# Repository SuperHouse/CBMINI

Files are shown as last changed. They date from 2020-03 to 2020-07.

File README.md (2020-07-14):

Chair Control Breakout Mini
===========================

Connects between an electric wheelchair input device and the chair
controller, so that the input device can be read by an Arduino and
redirected to another system.

The output can be isolated so that the chair won't receive the input
signals, preventing it from moving while the input is being used for
another purpose such as controlling a computer or remote control
device.

The breakout can send the output to either a connected USB host such
as a computer, or other devices via CAN bus so the wheelchair controls
can be used to fly a drone or drive a remote control car.

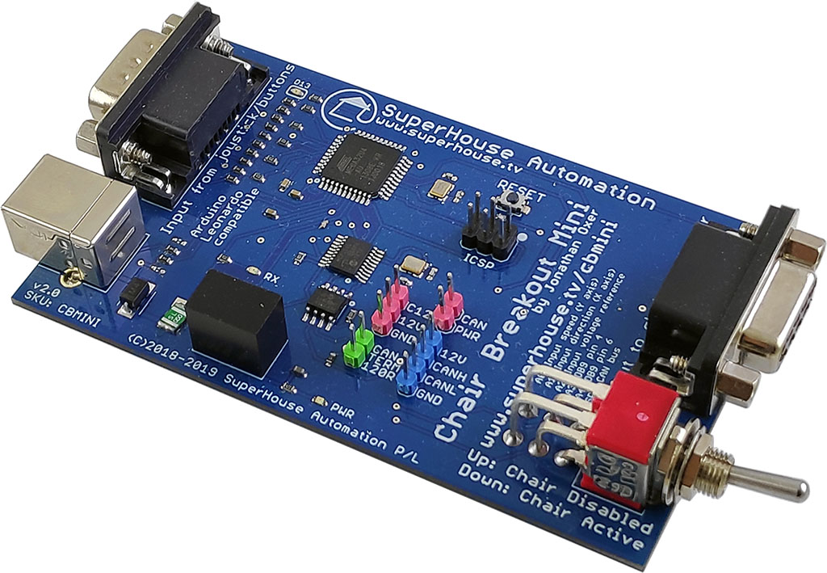
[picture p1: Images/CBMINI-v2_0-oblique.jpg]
Chair Breakout Mini


Features:

 * 1 x input device connection.
 * 1 x input device pass-through output
 * CAN bus
 * Can derives 12V power from the host wheelchair controller or separately

More information is available at:

  http://www.superhouse.tv/cbmini

Hardware
--------
The "Hardware" directory contains the PCB design as an EAGLE project.
EAGLE PCB design software is available from Autodesk free for
non-commercial use.

Firmware
--------
The "Firmware" directory contains example firmware as an Arduino
project.

Credits
-------
Jonathan Oxer jon@oxer.com.au

License
-------
Copyright 2017-2020 SuperHouse Automation Pty Ltd  www.superhouse.tv  

The hardware portion of this project is licensed under the TAPR Open
Hardware License (www.tapr.org/OHL). The "license" folder within this
repository contains a copy of this license in plain text format.

The software portion of this project is licensed under the Simplified
BSD License. The "licence" folder within this project contains a
copy of this license in plain text format.

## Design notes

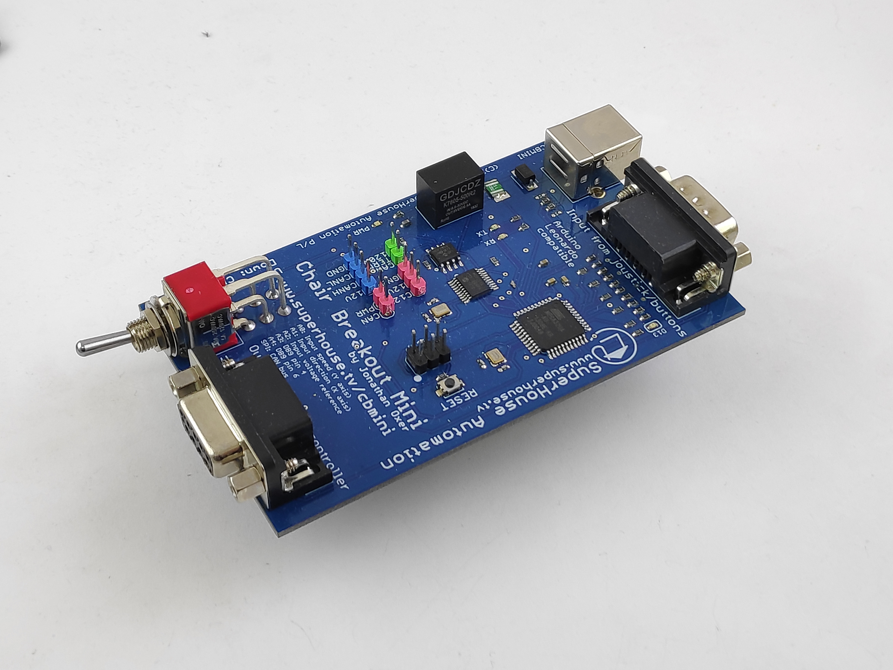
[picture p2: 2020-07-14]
Images/2019-11-09 11.39.07.jpg

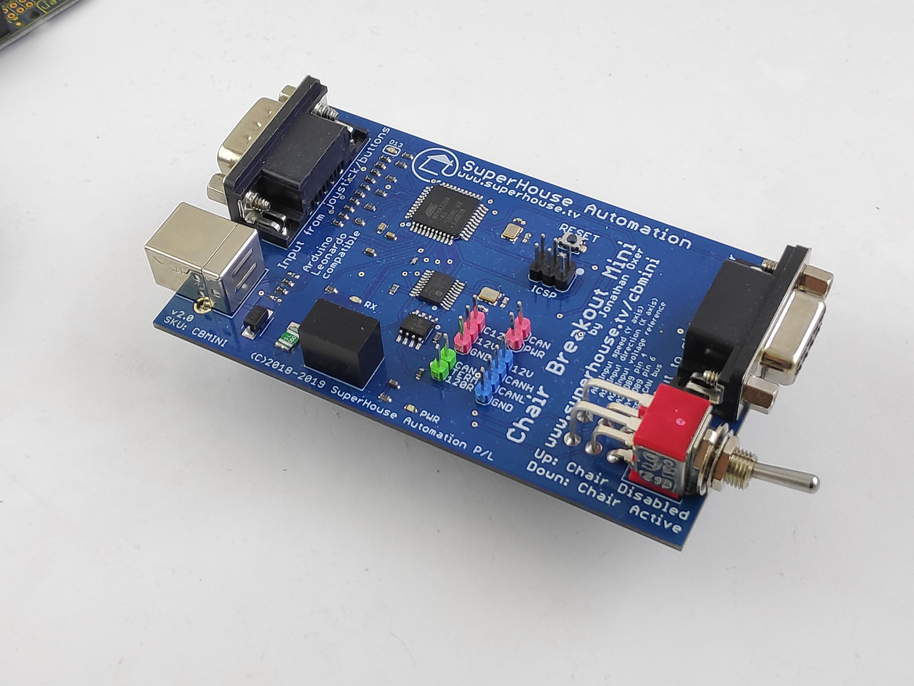
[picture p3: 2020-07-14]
Images/2019-11-09 11.39.31.jpg

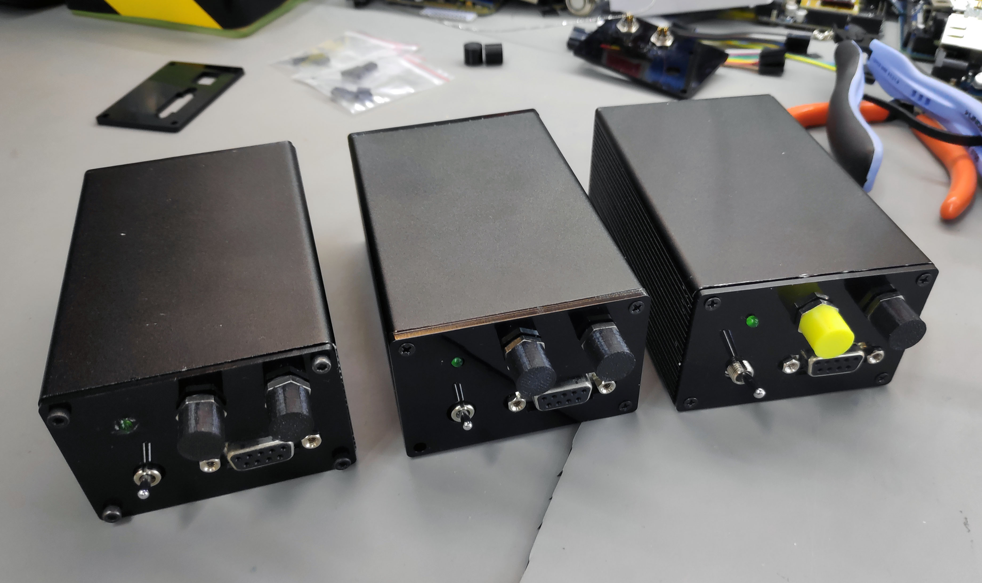
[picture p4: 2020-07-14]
Images/2019-04-25 10.59.25.jpg

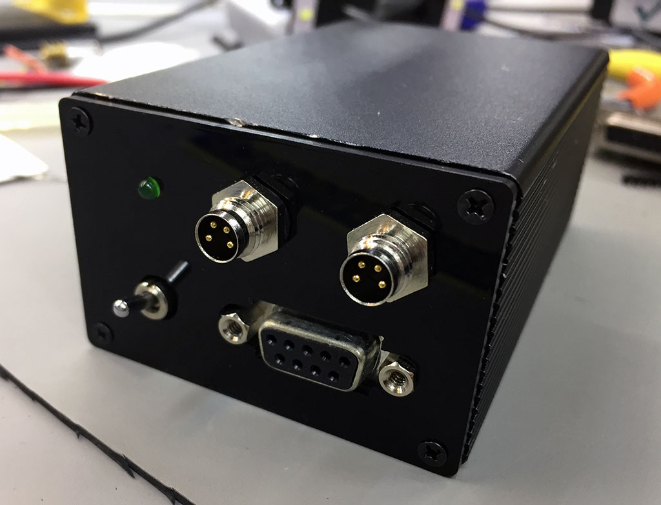
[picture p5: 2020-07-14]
Images/CBMINI-on-bench.jpg

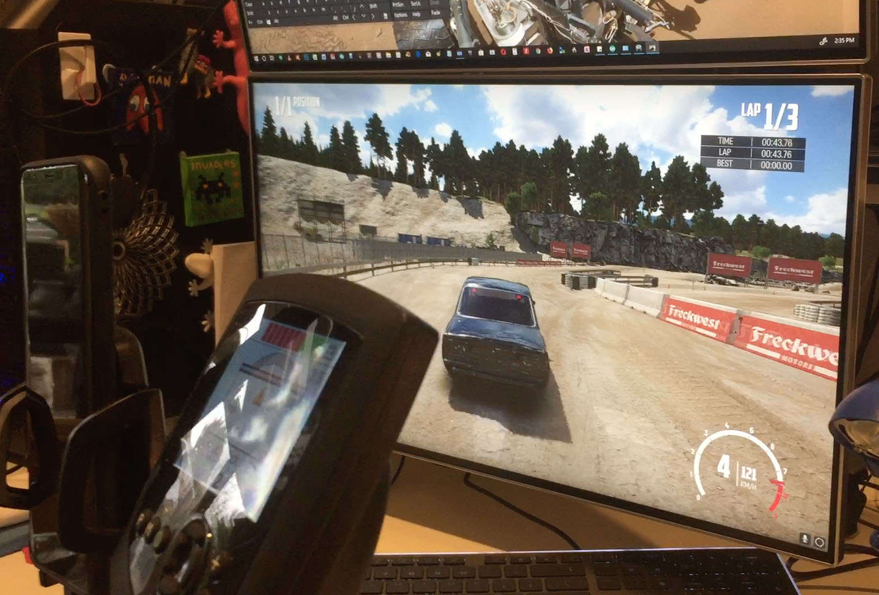
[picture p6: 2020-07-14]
Images/car-game.jpg

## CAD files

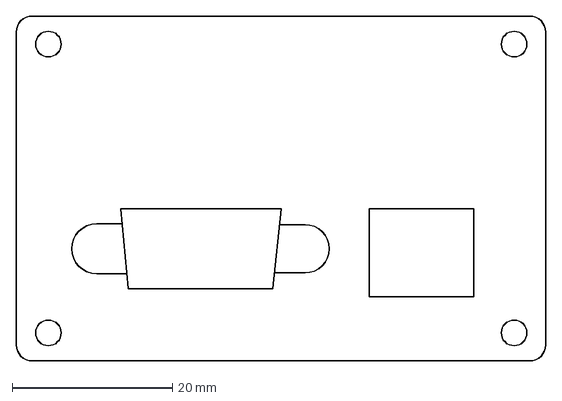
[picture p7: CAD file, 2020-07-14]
Enclosure/Left End Plate v8.dxf
66.0 x 43.0 mm

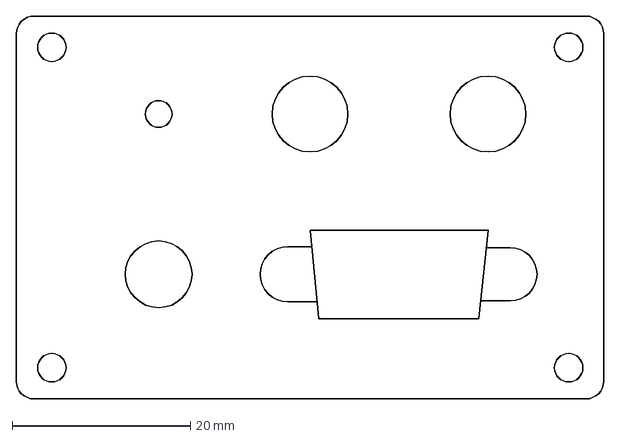
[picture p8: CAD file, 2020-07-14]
Enclosure/Right End Plate v6.dxf
66.0 x 43.0 mm

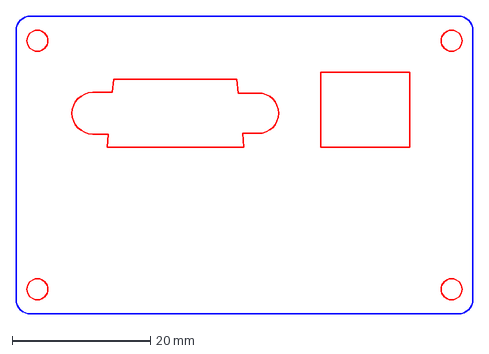
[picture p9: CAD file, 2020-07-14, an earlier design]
Enclosure/Left End Plate v5.dxf
66.2 x 43.2 mm

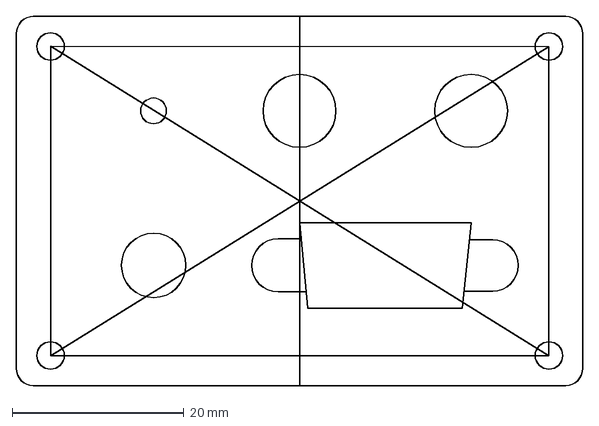
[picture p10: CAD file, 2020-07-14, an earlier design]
Enclosure/Right End Plate v5.dxf
66.0 x 43.0 mm

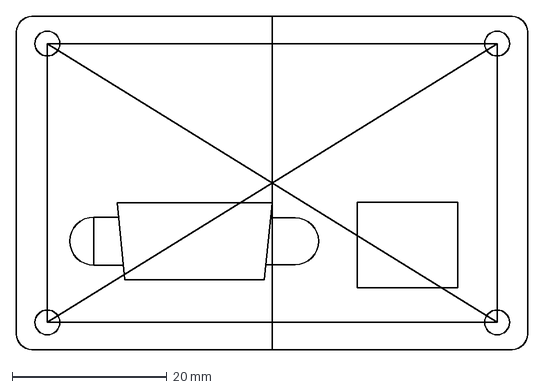
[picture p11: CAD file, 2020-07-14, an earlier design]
Enclosure/Left End Plate v7.dxf
66.0 x 43.0 mm

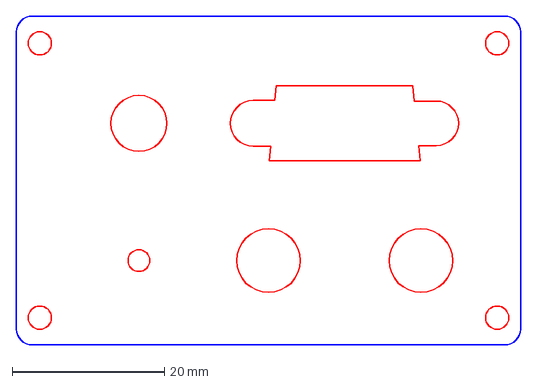
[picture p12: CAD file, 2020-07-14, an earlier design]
Enclosure/Right End Plate v3.dxf
66.2 x 43.2 mm

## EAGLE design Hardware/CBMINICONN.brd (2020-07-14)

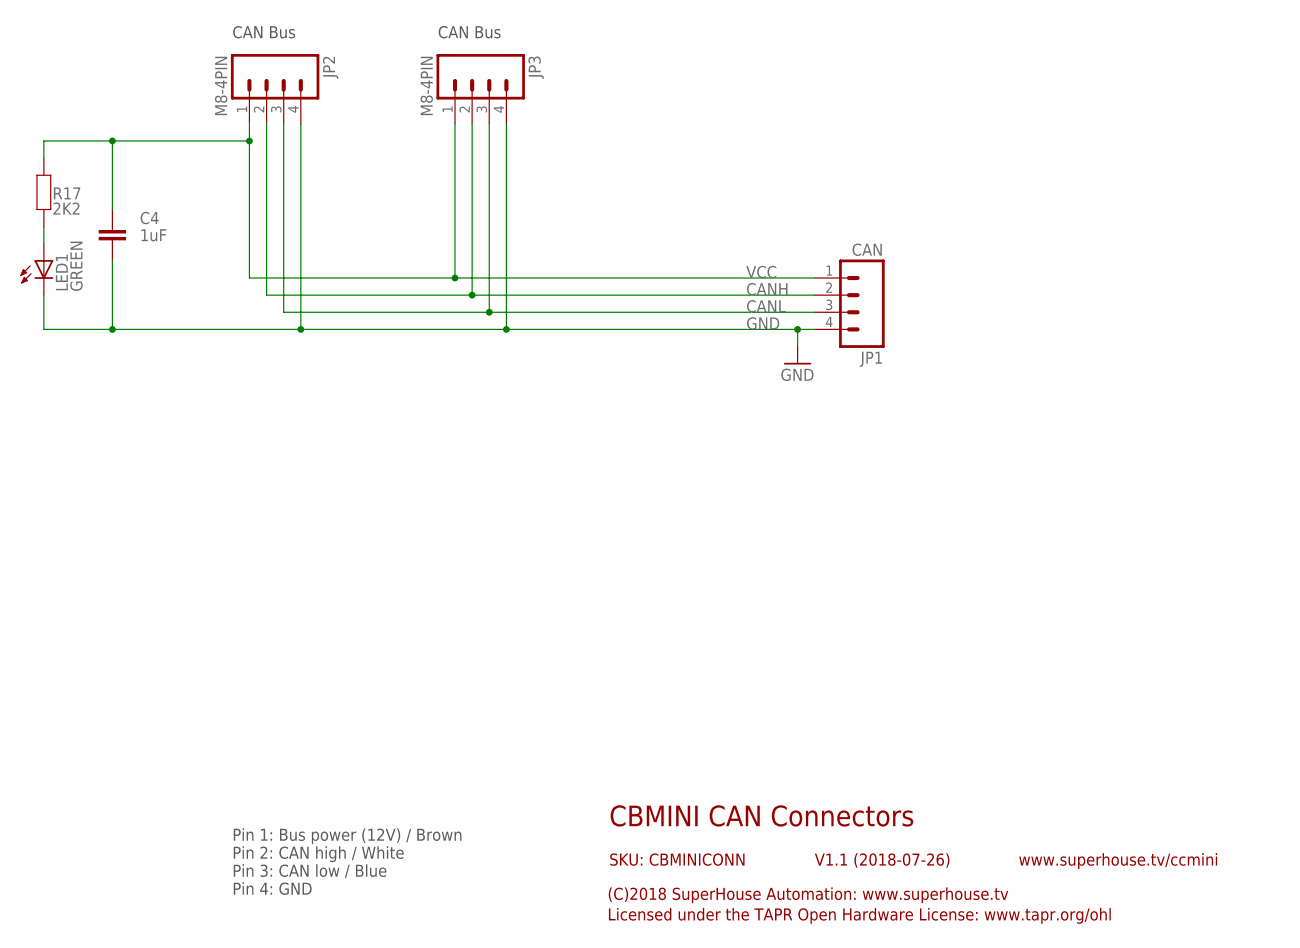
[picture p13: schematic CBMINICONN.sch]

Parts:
C4: 1uF; 0603
JP1: CAN; 1X04
JP2, JP3: M8-4PIN
LED1: GREEN; LED3MM
R17: 2K2; 0603

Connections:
CANH: JP1.2, JP2.2, JP3.2
CANL: JP1.3, JP2.3, JP3.3
GND: C4.1, JP1.4, JP2.4, JP3.4, LED1.K (C)
unnamed: LED1.A, R17.1
VCC: C4.2, JP1.1, JP2.1, JP3.1, R17.2

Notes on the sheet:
CBMINI CAN Connectors
V1.1 (2018-07-26)
SKU: CBMINICONN
(C)2018 SuperHouse Automation: www.superhouse.tv
Licensed under the TAPR Open Hardware License: www.tapr.org/ohl
www.superhouse.tv/ccmini
Pin 1: Bus power (12V) / Brown Pin 2: CAN high / White Pin 3: CAN low / Blue Pin 4: GND
CAN Bus

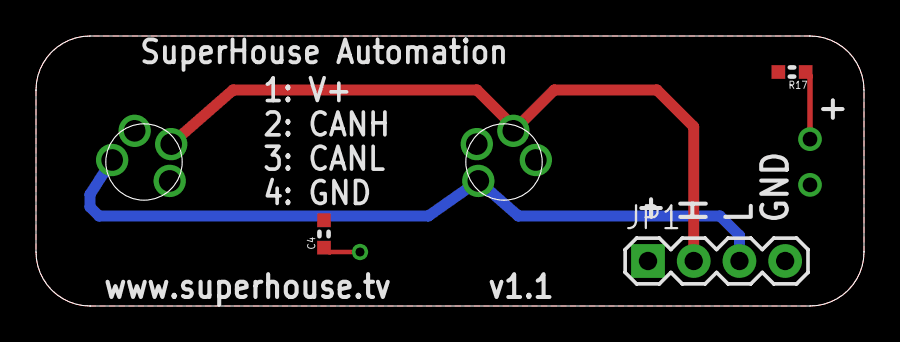
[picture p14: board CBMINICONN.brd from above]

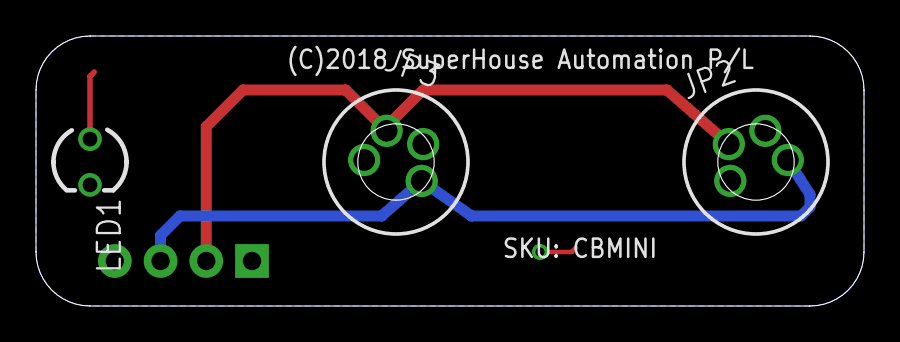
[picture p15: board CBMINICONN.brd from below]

Board: 2 copper layers, 46.0 x 15.0 mm, 6 parts (3 on the bottom side), 5 nets.

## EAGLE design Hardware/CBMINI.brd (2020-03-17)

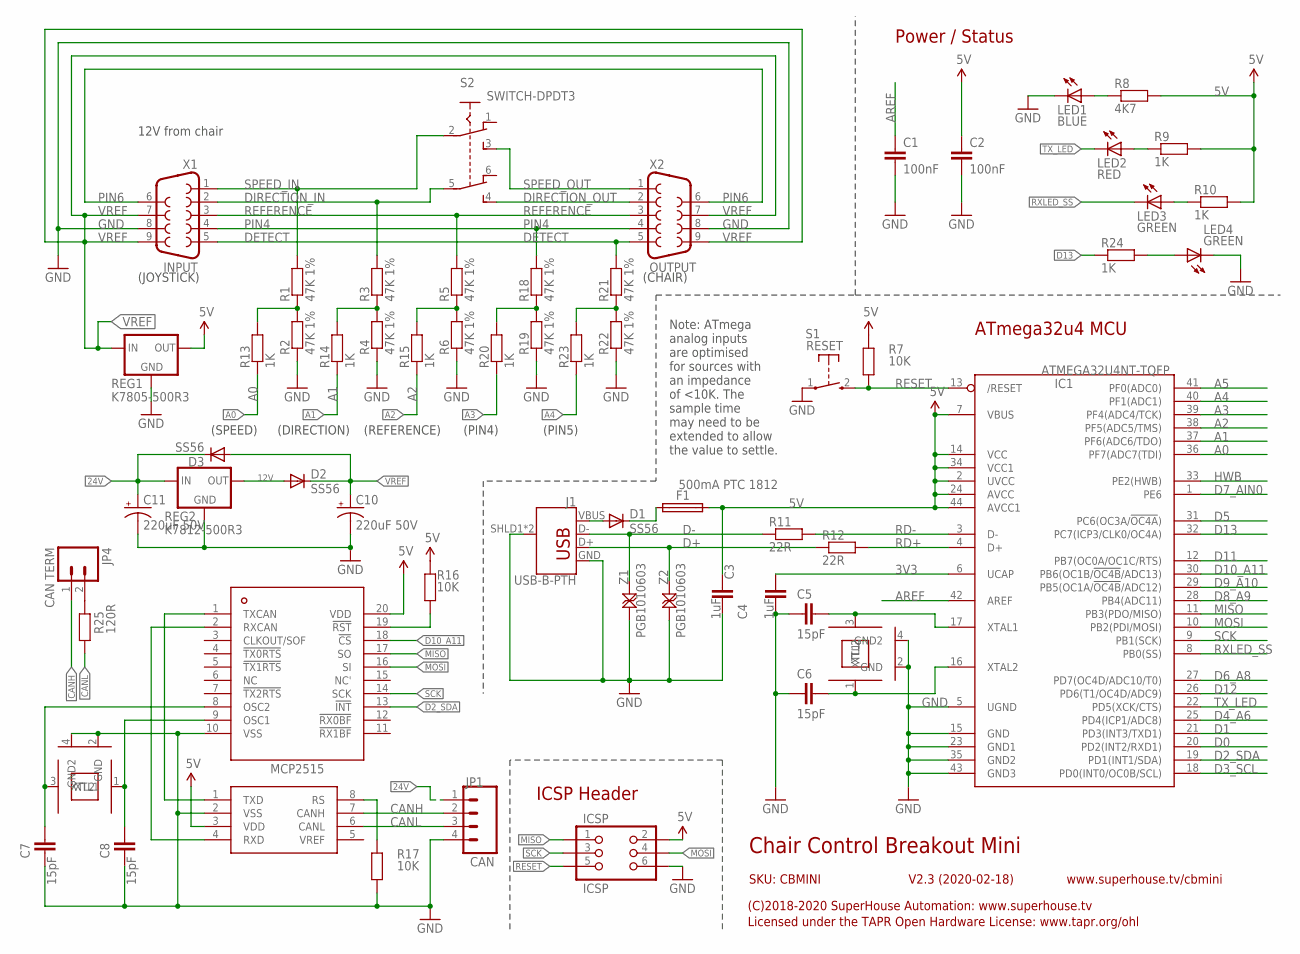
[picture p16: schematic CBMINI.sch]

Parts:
C1, C2: 100nF; C0603
C3, C4: 1uF; C0603
C5, C6, C7, C8: 15pF; C0603
C10, C11: 220uF 50V; PANASONIC_G
D1, D2, D3: SS56; SMA-DIODE
F1: 500mA PTC 1812; 1812
IC1: ATMEGA32U4NT-TQFP; TQFP44
IC2: MCP2515; TSSOP20
IC3: MCP2551; SO08
ICSP: ICSP; 2X03-ICSP
J1: USB-B-PTH
JP1: CAN; 1X04-P
JP4: CAN TERM; 1X02-P
LED1: BLUE; LED-0603
LED2: RED; LED-0603
LED3, LED4: GREEN; LED-0603
R1, R2, R3, R4, R5, R6, R18, R19, R21, R22: 47K 1%; R0603
R7, R16, R17: 10K; R0603
R8: 4K7; R0603
R9, R10, R13, R14, R15, R20, R23, R24: 1K; R0603
R11, R12: 22R; R0603
R25: 120R; R0603
REG1: K7805-500R3; K78XX-500R3
REG2: K7812-500R3; K78XX-500R3
S1: RESET; TACTILE_SMT_3X4X2
S2: SWITCH-DPDT3; 7201SD9AV2BE
X1: INPUT; DB9-PCB-PLUG
X2: OUTPUT; DB9-PCB-SOCKET
XTL1, XTL2: 16MHz; CRYSTAL-SMD-3X2
Z1, Z2: PGB1010603; TVS0603

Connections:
3V3: C4.2, IC1.6 (UCAP)
5V: C2.1, C3.1, F1.2, IC1.2 (UVCC), IC1.7 (VBUS), IC1.14 (VCC), IC1.24 (AVCC), IC1.34 (VCC1), IC1.44 (AVCC1), IC2.20 (VDD), IC3.3 (VDD), ICSP.2, R7.2, R8.2, R9.2, R10.2, R16.2, REG1.3 (OUT)
12V: D2.A, REG2.3 (OUT)
24V: C11.+, D3.C, JP1.1, REG2.1 (IN)
A0: IC1.36 (PF7(ADC7(TDI)), R13.1
A1: IC1.37 (PF6(ADC6/TDO)), R14.1
A2: IC1.38 (PF5(ADC5/TMS)), R15.1
A3: IC1.39 (PF4(ADC4/TCK)), R20.1
A4: IC1.40 (PF1(ADC1)), R23.1
A5: IC1.41 (PF0(ADC0))
AREF: C1.1, IC1.42 (AREF)
CANH: IC3.7 (CANH), JP1.2, JP4.1
CANL: IC3.6 (CANL), JP1.3, R25.1
D0: IC1.20 (PD2(INT2/RXD1))
D1: IC1.21 (PD3(INT3/TXD1))
D2_SDA: IC1.19 (PD1(INT1/SDA)), IC2.13 (!INT)
D3_SCL: IC1.18 (PD0(INT0/OC0B/SCL))
D4_A6: IC1.25 (PD4(ICP1/ADC8))
D5: IC1.31 (PC6(OC3A/!OC4A!))
D6_A8: IC1.27 (PD7(OC4D/ADC10/T0))
D7_AIN0: IC1.1 (PE6)
D8_A9: IC1.28 (PB4(ADC11))
D9_A10: IC1.29 (PB5(OC1A/!OC4B!/ADC12))
D10_A11: IC1.30 (PB6(OC1B/!OC4B!/ADC13)), IC2.18 (!CS)
D11: IC1.12 (PB7(OC0A/OC1C/RTS))
D12: IC1.26 (PD6(T1/OC4D/ADC9))
D13: IC1.32 (PC7(ICP3/CLK0/OC4A)), R24.1
D+: J1.D+, R12.1, Z2.2
D-: J1.D-, R11.1, Z1.2
DETECT: R21.2, X1.5, X2.5
DIRECTION_IN: R3.2, S2.5, X1.2
DIRECTION_OUT: S2.4, X2.2
GND: C1.2, C2.2, C3.2, C4.1, C5.1, C6.1, C7.1, C8.1, C10.-, C11.-, IC1.5 (UGND), IC1.15 (GND), IC1.23 (GND1), IC1.35 (GND2), IC1.43 (GND3), IC2.10 (VSS), IC3.2 (VSS), ICSP.6, J1.GND, J1.SHLD1 (SHIELD), J1.SHLD2 (SHIELD), JP1.4, LED1.C, LED4.C, R2.1, R4.1, R6.1, R17.1, R19.1, R22.1, REG1.2 (GND), REG2.2 (GND), S1.1, X1.8, X2.8, XTL1.2 (GND), XTL1.4 (GND2), XTL2.2 (GND), XTL2.4 (GND2), Z1.1, Z2.1
HWB: IC1.33 (PE2(HWB))
MISO: IC1.11 (PB3(PDO/MISO)), IC2.17 (SO), ICSP.1
MOSI: IC1.10 (PB2(PDI/MOSI)), IC2.16 (SI), ICSP.4
unnamed: LED4.A, R24.2
unnamed: R1.1, R2.2, R13.2
unnamed: R3.1, R4.2, R14.2
unnamed: R5.1, R6.2, R15.2
unnamed: LED1.A, R8.1
unnamed: LED2.A, R9.1
unnamed: LED3.A, R10.1
unnamed: IC2.1 (TXCAN), IC3.1 (TXD)
unnamed: IC2.19 (!RST), R16.1
unnamed: C5.2, IC1.17 (XTAL1), XTL1.3 (XTL2)
unnamed: C6.2, IC1.16 (XTAL2), XTL1.1 (XTL1)
unnamed: IC2.2 (RXCAN), IC3.4 (RXD)
unnamed: C8.2, IC2.9 (OSC1), XTL2.1 (XTL1)
unnamed: IC3.8 (RS), R17.2
unnamed: D1.C, F1.1
unnamed: C7.2, IC2.8 (OSC2), XTL2.3 (XTL2)
unnamed: R18.1, R19.2, R20.2
unnamed: JP4.2, R25.2
unnamed: R21.1, R22.2, R23.2
PIN4: R18.2, X1.4, X2.4
PIN6: X1.6, X2.6
RD+: IC1.4 (D+), R12.2
RD-: IC1.3 (D-), R11.2
REFERENCE: R5.2, X1.3, X2.3
RESET: IC1.13 (/RESET), ICSP.5, R7.1, S1.2 (S)
RXLED_SS: IC1.8 (PB0(SS)), LED3.C
SCK: IC1.9 (PB1(SCK)), IC2.14 (SCK), ICSP.3
SPEED_IN: R1.2, S2.2, X1.1
SPEED_OUT: S2.3, X2.1
TX_LED: IC1.22 (PD5(XCK/CTS)), LED2.C
USB+: D1.A, J1.VBUS
VREF: C10.+, D2.C, D3.A, REG1.1 (IN), X1.7, X1.9, X2.7, X2.9

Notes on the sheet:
(JOYSTICK)
(CHAIR)
Note: ATmega analog inputs are optimised for sources with an impedance of <10K. The sample time may need to be extended to allow the value to settle.
(SPEED)
(DIRECTION)
(REFERENCE)
ICSP Header
ATmega32u4 MCU
Chair Control Breakout Mini
V2.3 (2020-02-18)
SKU: CBMINI
(C)2018-2020 SuperHouse Automation: www.superhouse.tv
Licensed under the TAPR Open Hardware License: www.tapr.org/ohl
www.superhouse.tv/cbmini
Power / Status
12V from chair
(PIN4)
(PIN5)

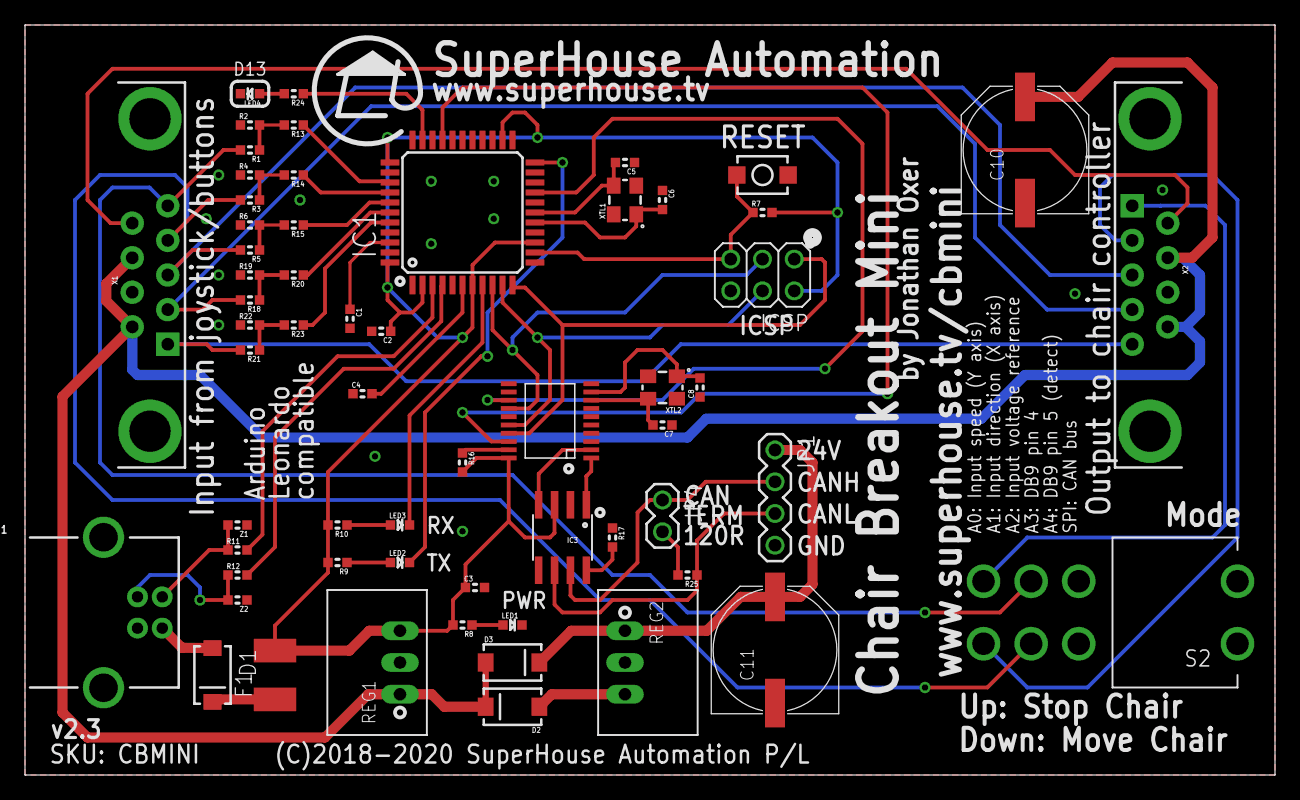
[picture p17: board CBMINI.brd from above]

Board: 2 copper layers, 100.0 x 60.0 mm, 60 parts (0 on the bottom side), 55 nets.

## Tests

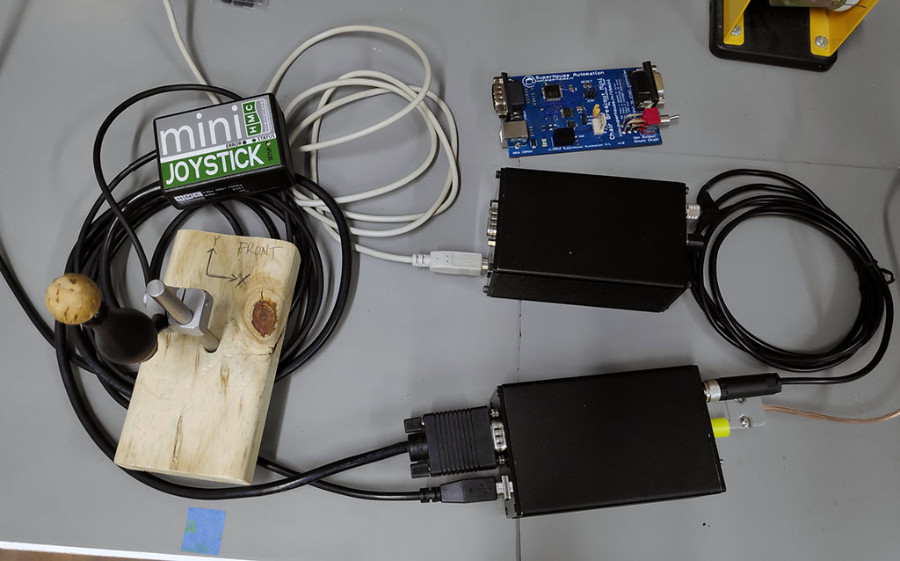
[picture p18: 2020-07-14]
Images/CBMINI-testing.jpg

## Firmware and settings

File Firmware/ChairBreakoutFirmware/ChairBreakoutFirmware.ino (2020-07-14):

/**
   Firmware for the Chair Breakout Mini by SuperHouse Automation Pty Ltd

   Reads from:
    1. Button box
    2. CAN bus
    3. Wheelchair joystick

   Sends to:
    1. Keyboard emulation on USB with keypresses
    2. Transmit events over CAN bus to other connected devices
    3. Game controller emulation on USB with both joystick and button events on CAN

   CAN packet IDs:
    0x12: X axis value
    0x13: Y axis value
    0x14: Button events are sent, like "v+" for press of v and "v-" for release of v

   By Chris Fryer (chris.fryer78@gmail.com) and Jonathan Oxer (jon@superhouse.tv)
   www.superhouse.tv
 **/

/*--------------------------- Configuration ------------------------------*/
// Configuration should be done in the included file:
#include "config.h"

/*--------------------------- Libraries ----------------------------------*/
#include <Joystick.h>    // Joystick emulation: https://github.com/MHeironimus/ArduinoJoystickLibrary
#include <Keyboard.h>    // Keyboard emulation
#include <CAN.h>         // CAN bus communication: https://github.com/sandeepmistry/arduino-CAN (available in library manager)

/*--------------------------- Global Variables ---------------------------*/
// Button input
uint16_t g_button_value[5]          = { 0, 0, 0, 0, 0 };       // Analog reading from input
uint16_t g_button_previous_value[5] = { 0, 0, 0, 0, 0 };      // Analog reading from input
uint8_t g_button_pin[5]             = { BUTTON_1_PIN, BUTTON_2_PIN, BUTTON_3_PIN, BUTTON_4_PIN, BUTTON_5_PIN };

// Joystick input
uint8_t g_joystick_present         = false; // Whether a joystick has been detected
uint16_t g_x_axis_delta            = 0;     // Offset of X axis compared to reference voltage
uint16_t g_y_axis_delta            = 0;     // Offset of Y axis compared to reference voltage
uint16_t g_joystick_reading        = 0;     // ?
uint8_t g_throttle_position        = 0;     // Store the current throttle position
uint16_t g_voltage_ref_value       = 0;     // Reference voltage reading from joystick;

// Reporting
uint32_t g_last_serial_report_time = 0;     // ms timestamp of last report to serial console
uint32_t g_last_can_report_time    = 0;     // ms timestamp of last report to CAN bus

// CAN bus
char g_can_msg[12];                         // Buffer for CAN messages
char g_incoming_message_buffer[12];         // Buffer for incoming CAN messages

/*--------------------------- Function Signatures ---------------------------*/
void reportViaSerial();
void readOneButton(uint8_t button_id);
void readButtons();
void readJoystick();

/*--------------------------- Instantiate Global Objects --------------------*/
// Virtual joystick device
Joystick_ Joystick(JOYSTICK_DEFAULT_REPORT_ID, JOYSTICK_TYPE_GAMEPAD,
                   1, 0,                  // Button Count, Hat Switch Count
                   true, true, false,     // X and Y, but no Z Axis
                   false, false, false,   // No Rx, Ry, or Rz
                   false, true,           // No rudder, but enable throttle
                   false, false, false);  // No accelerator, brake, or steering

/*--------------------------- Program ---------------------------------------*/
/**
   Setup
*/
void setup() {
  Serial.begin(115200);
  //while (!Serial) {
  //  ; // wait for serial port to connect. Needed for native USB port only
  //}
  delay(2500); // Delay to allow serial port time to connect if it's present,
  // but continue anyway if it's not
  Serial.println("Wheelchair joystick breakout v2.2");

  pinMode(BUTTON_1_PIN, INPUT_PULLUP);
  pinMode(BUTTON_2_PIN, INPUT_PULLUP);
  pinMode(BUTTON_3_PIN, INPUT_PULLUP);
  pinMode(BUTTON_4_PIN, INPUT_PULLUP);
  pinMode(BUTTON_5_PIN, INPUT_PULLUP);

  if (!CAN.begin(CAN_BUS_SPEED)) {
    Serial.println("Starting CAN failed!");
    while (1);
  } else {
    Serial.println("Started CAN OK");
  }

  uint16_t inputValue = analogRead(BUTTON_1_PIN);
  if (inputValue > JOYSTICK_PRESENT_LEVEL)
  {
    g_joystick_present = true;
  }

  // Begin joystick emulation or keyboard emulation, depending on attached device
  if (g_joystick_present)
  {
    // Joystick found, so initialise joystick emulation
    Serial.println(F("Joystick mode"));
    Joystick.begin();
    Joystick.setXAxisRange(-JOYSTICK_AXIS_RANGE, JOYSTICK_AXIS_RANGE);
    Joystick.setYAxisRange(-JOYSTICK_AXIS_RANGE, JOYSTICK_AXIS_RANGE);
    Joystick.setThrottleRange(-127, 127);
  } else {
    // No joystick found, so initialise keyboard emulation
    Serial.println(F("Button box mode"));
    Keyboard.begin();
  }
  Serial.println("Ready");
}

/**
   Loop
*/
void loop() {
  // Check for CAN messages
  processCAN();

  if (g_joystick_present)
  {
    readJoystick();
  } else {
    readButtons();
  }
  reportViaSerial();
}

/**

*/
void reportViaSerial()
{
  uint32_t current_time = millis();
  if ((current_time - g_last_serial_report_time) > JOYSTICK_DEBUG_INTERVAL)
  {
    if (JOYSTICK_DEBUG)
    {
      Serial.print("T:");
      Serial.println(g_throttle_position);
      g_last_serial_report_time = current_time;
    }
  }
}

/**
   Read one of the input buttons
*/
void readOneButton(uint8_t button_id)
{
  g_button_value[button_id] = analogRead(g_button_pin[button_id]);

  if (BUTTONS_DEBUG)
  {
    Serial.print(F("Button ID: "));
    Serial.print(button_id);
    Serial.print(F(" Button: "));
    Serial.print(g_button_character[button_id]);
    Serial.print(F(": "));
    Serial.println(g_button_value[button_id]);
  }

  // Detect transition from unpressed to pressed
  if ((g_button_value[button_id] <= BUTTON_TRIGGER_LEVEL) && (g_button_previous_value[button_id] > BUTTON_TRIGGER_LEVEL))
  {
    Keyboard.press(g_button_character[button_id]);

    g_can_msg[0] = g_button_character[button_id];
    g_can_msg[1] = '+';          // key press
    CAN.beginPacket(0x14);       // Packet ID 0x14
    for (uint8_t i = 0; i < 12; i++) // Hard coded length to 12 bytes. Make variable? Single byte?
    {
      CAN.write(g_can_msg[i]);
    }
    CAN.endPacket();
    if (BUTTONS_DEBUG)
    {
      Serial.print(F("Button: "));
      Serial.print(g_button_character[button_id]);
      Serial.println(F(" press"));
    }
  }
  // Detect transition from pressed to unpressed
  if ((g_button_value[button_id] > BUTTON_TRIGGER_LEVEL) && (g_button_previous_value[button_id] <= BUTTON_TRIGGER_LEVEL))
  {
    Keyboard.release(g_button_character[button_id]);

    g_can_msg[0] = g_button_character[button_id];
    g_can_msg[1] = '-';          // key release
    CAN.beginPacket(0x14);       // Packet ID 0x14
    for (uint8_t i = 0; i < 12; i++) // Hard coded length to 12 bytes. Make variable? Single byte?
    {
      CAN.write(g_can_msg[i]);
    }
    CAN.endPacket();
    if (BUTTONS_DEBUG)
    {
      Serial.print(F("Button: "));
      Serial.print(g_button_character[button_id]);
      Serial.println(F(" release"));
    }
  }
  g_button_previous_value[button_id] = g_button_value[button_id];
}

/**
  Read each of the possible input buttons
*/
void readButtons()
{
  readOneButton(0);
  readOneButton(1);
  readOneButton(2);
  readOneButton(3);
  readOneButton(4);
}

/**
  Process messages received via CAN bus
*/
void processCAN()
{
  // Try to parse packet
  uint8_t packet_size = CAN.parsePacket();

  if (packet_size) {
    // Received a packet
    if (CAN_DEBUG)
    {
      Serial.print("Received packet with id 0x");
      Serial.print(CAN.packetId(), HEX);
      Serial.print(" and length ");
      Serial.println(packet_size);
    }

    if (CAN_DEBUG)
    {
      Serial.print(">");
    }
    uint8_t i = 0;
    while (CAN.available()) {
      char msg_char = (char)CAN.read();
      if (CAN_DEBUG)
      {
        Serial.print(msg_char);
      }
      g_incoming_message_buffer[i] = msg_char;
      i++;
    }
    if (CAN_DEBUG)
    {
      Serial.print("<");
      Serial.println();
    }

    if (!g_joystick_present)
    {
      if (g_incoming_message_buffer[1] == '+')
      {
        Keyboard.press(g_incoming_message_buffer[0]);
      }

      if (g_incoming_message_buffer[1] == '-')
      {
        Keyboard.release(g_incoming_message_buffer[0]);
      }
    }


    // Check for specific keys if we're in joystick mode, to use for throttle up and down
    if (g_incoming_message_buffer[0] == 'v')
    {
      g_throttle_position = g_throttle_position + THROTTLE_INCREMENT;

      if (g_throttle_position > 127)
      {
        g_throttle_position = 127;
      }
    }
    if (g_incoming_message_buffer[0] == 'w')
    {
      g_throttle_position = g_throttle_position - THROTTLE_INCREMENT;
      if (g_throttle_position < -127)
      {
        g_throttle_position = -127;
      }
    }
  }
}

/**
  Read the joystick position
*/
void readJoystick()
{
  uint32_t current_time = millis();
  g_voltage_ref_value = analogRead(VREF_PIN);

  g_joystick_reading = analogRead(Y_AXIS_PIN);
  if (g_joystick_reading > (g_voltage_ref_value + CENTER_DEAD_SPOT))
  {
    g_y_axis_delta = g_voltage_ref_value - g_joystick_reading + CENTER_DEAD_SPOT;
  }
  if (g_joystick_reading < (g_voltage_ref_value - CENTER_DEAD_SPOT))
  {
    g_y_axis_delta = g_voltage_ref_value - g_joystick_reading - CENTER_DEAD_SPOT;
  }

  g_joystick_reading = analogRead(X_AXIS_PIN);
  if (g_joystick_reading > (g_voltage_ref_value + CENTER_DEAD_SPOT))
  {
    g_x_axis_delta = g_voltage_ref_value - g_joystick_reading + CENTER_DEAD_SPOT;
  }
  if (g_joystick_reading < (g_voltage_ref_value - CENTER_DEAD_SPOT))
  {
    g_x_axis_delta = g_voltage_ref_value - g_joystick_reading - CENTER_DEAD_SPOT;
  }

  /* Send output to joystick HID */
  Joystick.setYAxis(g_y_axis_delta * -1);  // Y axis is reversed
  Joystick.setXAxis(g_x_axis_delta);
  if (JOYSTICK_DEBUG)
  {
    Serial.println(g_x_axis_delta);
  }

  Joystick.setThrottle(g_throttle_position);

  /* Send output to CAN bus */
  if (current_time > (g_last_can_report_time + CAN_MESSAGE_INTERVAL))
  {
    int16_t xLength = (g_x_axis_delta == 0 ? 1 : ((int16_t)(log10(fabs(g_x_axis_delta)) + 1) + (g_x_axis_delta < 0 ? 1 : 0)));
    int16_t yLength = (g_y_axis_delta == 0 ? 1 : ((int16_t)(log10(fabs(g_y_axis_delta)) + 1) + (g_y_axis_delta < 0 ? 1 : 0)));

    //Serial.println(xLength);
    sprintf(g_can_msg, "%d", g_x_axis_delta);
    CAN.beginPacket(0x12);     // Packet ID 0x12 for X axis
    for (uint8_t i = 0; i < xLength; i++)
    {
      CAN.write(g_can_msg[i]);
    }
    CAN.endPacket();

    sprintf(g_can_msg, "%d", g_y_axis_delta);
    CAN.beginPacket(0x13);     // Packet ID 0x13 for Y axis
    for (uint8_t i = 0; i < yLength; i++)
    {
      CAN.write(g_can_msg[i]);
    }
    CAN.endPacket();
    g_last_can_report_time = current_time;
  }
}

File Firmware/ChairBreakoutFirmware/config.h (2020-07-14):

/* -------------------------- User configuration ----------------------------*/
// Button options
char g_button_character[5] = { 'w', 'z', 't', 'u', 'v' }; // Character to send when each key is pressed

// Joystick options
#define THROTTLE_INCREMENT         20  // Move this many steps when button is pressed
#define CENTER_DEAD_SPOT            0  // +/- this value from 0 gives 0 output

// CAN options
#define CAN_MESSAGE_INTERVAL       50  // Message interval for CAN in milliseconds
#define CAN_BUS_SPEED           500E3  // 500kbps

// Debug options
#define CAN_DEBUG               false  // Report CAN events to serial console
#define BUTTONS_DEBUG           false  // Report button events to serial console
#define JOYSTICK_DEBUG          false  // Report joystick values to serial console
#define JOYSTICK_DEBUG_INTERVAL   500  // Reporting interval for debug messages in milliseconds

/* -------------------------- Hardware setup --------------------------------*/
// Pin connections for button box input
#define BUTTON_1_PIN            A0
#define BUTTON_2_PIN            A1
#define BUTTON_3_PIN            A2
#define BUTTON_4_PIN            A3
#define BUTTON_5_PIN            A4

// Inputs sit about 572 normally, drop to about 406 when activated
#define BUTTON_TRIGGER_LEVEL 500

// Pin connections for joystick input
#define Y_AXIS_PIN              A0
#define X_AXIS_PIN              A1
#define VREF_PIN                A2

#define JOYSTICK_AXIS_RANGE     75  //#define JOYSTICK_AXIS_RANGE 127
#define JOYSTICK_PRESENT_LEVEL 700  // When a joystick is connected, it pulls the input voltage above this level

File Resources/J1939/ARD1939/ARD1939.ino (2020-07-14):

// ------------------------------------------------------------------------
// ARD1939 - SAE J1939 Protocol Stack for Arduino Uno and Mega2560
// ------------------------------------------------------------------------
//
// IMPORTANT: Depending on the CAN shield used for this programming sample,
//             please make sure you set the proper CS pin in ARD1939.h.
//
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
#include <stdlib.h>
#include <inttypes.h>
#include <SPI.h>

#include "ARD1939.h"

ARD1939 j1939;

int nCounter = 0;

// ------------------------------------------------------------------------
//  Setup routine runs on power-up or reset
// ------------------------------------------------------------------------
void setup() 
{
  // Set the serial interface baud rate
  Serial.begin(MONITOR_BAUD_RATE);
  
  // Initialize the J1939 protocol including CAN settings
  if(j1939.Init(SYSTEM_TIME) == 0)
    Serial.print("CAN Controller Init OK.\n\r\n\r");
  else
    Serial.print("CAN Controller Init Failed.\n\r");
    
 // Set the preferred address and address range
 j1939.SetPreferredAddress(SA_PREFERRED);
 j1939.SetAddressRange(ADDRESSRANGEBOTTOM, ADDRESSRANGETOP);
 
 // Set the message filter
 //j1939.SetMessageFilter(59999);
 
 //j1939.SetMessageFilter(65242);
 //j1939.SetMessageFilter(65259);
 //j1939.SetMessageFilter(65267);
 
 // Set the NAME
 j1939.SetNAME(NAME_IDENTITY_NUMBER,
               NAME_MANUFACTURER_CODE,
               NAME_FUNCTION_INSTANCE,
               NAME_ECU_INSTANCE,
               NAME_FUNCTION,
               NAME_VEHICLE_SYSTEM,
               NAME_VEHICLE_SYSTEM_INSTANCE,
               NAME_INDUSTRY_GROUP,
               NAME_ARBITRARY_ADDRESS_CAPABLE);
               
}// end setup

// ------------------------------------------------------------------------
// Main Loop - Arduino Entry Point
// ------------------------------------------------------------------------
void loop()
{
  // J1939 Variables
  byte nMsgId;
  byte nDestAddr;
  byte nSrcAddr;
  byte nPriority;
  byte nJ1939Status;
  
  int nMsgLen;
  
  long lPGN;
  
  byte pMsg[J1939_MSGLEN];
  
  // Variables for proof of concept tests
  //byte msgFakeNAME[] = {0, 0, 0, 0, 0, 0, 0, 0};
  byte msgLong[] = {0x31, 0x32, 0x33, 0x34, 0x35, 0x36, 0x37, 0x38, 0x39, 0x40, 0x41, 0x42, 0x43, 0x44, 0x45};
  
  // Establish the timer base in units of milliseconds
  delay(SYSTEM_TIME);
  
  // Call the J1939 protocol stack
  nJ1939Status = j1939.Operate(&nMsgId, &lPGN, &pMsg[0], &nMsgLen, &nDestAddr, &nSrcAddr, &nPriority);
  
  /*
  // Block certain claimed addresses
  if(nMsgId == J1939_MSG_PROTOCOL)
  {
    if(lPGN == 0x00EE00)
    {
      if(nSrcAddr >= 129 && nSrcAddr <= 134)
        j1939.Transmit(6, 0x00EE00, nSrcAddr, 255, msgFakeNAME, 8);
    
    }// end if
    
  }// end if
  */
  
  /*
  // Send out a periodic message with a length of more than 8 bytes
  // BAM Session
  if(nJ1939Status == NORMALDATATRAFFIC)
  {
    nCounter++;
    
    if(nCounter == (int)(5000/SYSTEM_TIME))
    {
      nSrcAddr = j1939.GetSourceAddress();
      j1939.Transmit(6, 59999, nSrcAddr, 255, msgLong, 15);
      nCounter = 0;
      
    }// end if
  
  }// end if
  */
  
  
  // Send out a periodic message with a length of more than 8 bytes
  // RTS/CTS Session
  if(nJ1939Status == NORMALDATATRAFFIC)
  {
    nCounter++;
    
    if(nCounter == (int)(5000/SYSTEM_TIME))
    {
      nSrcAddr = j1939.GetSourceAddress();
      j1939.Transmit(6, 59999, nSrcAddr, 0x33, msgLong, 15);
      nCounter = 0;
      
    }// end if
  
  }// end if
  
  
  // Check for reception of PGNs for our ECU/CA
  if(nMsgId == J1939_MSG_APP)
  {
    // Check J1939 protocol status
    switch(nJ1939Status)
    {
      case ADDRESSCLAIM_INPROGRESS:
      
        break;
        
      case NORMALDATATRAFFIC:
      
        // Determine the negotiated source address
        //byte nAppAddress;
        //nAppAddress = j1939.GetSourceAddress();
        
       break;
        
      case ADDRESSCLAIM_FAILED:
      
        break;
      
    }// end switch(nJ1939Status)
    
  }// end if
    
}// end loop

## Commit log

2020-03-17 Isolation diodes between CAN and chair power, and switched parts to SuperHouse libraries for v2.3 release
    [CBMINI.brd, CBMINI.sch]
2020-07-14 Start of major project restructure to merge everything together
    [CBMINI.brd, CBMINI.sch, CBMINICONN.brd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]

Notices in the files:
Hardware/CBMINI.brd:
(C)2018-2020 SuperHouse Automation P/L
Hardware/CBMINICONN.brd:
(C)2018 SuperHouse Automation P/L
